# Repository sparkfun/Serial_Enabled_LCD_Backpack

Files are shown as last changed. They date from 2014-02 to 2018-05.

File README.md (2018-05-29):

Serial Enabled LCD Backpack
===========================

Serial Enabled LCD Backpack (https://cdn.sparkfun.com/assets/parts/2/0/0/00258-01a.jpg)

[*Serial Enabled LCD Backpack (LCD-00258)*](https://www.sparkfun.com/products/258)

This PIC-based serial enabled LCD backpack allows you to control a parallel based LCD over a single-wire serial interface. It is compatible with 16x2 LCDs and 20x4 LCDs.

Repository Contents
-------------------

* **/Firmware**
  * **/Arduino_Examples** - Arduino example code to control the PIC-based serial enabled LCD
  * **/Default_Firmware** - Any default firmware on the PIC that the part ships with for different size LCD screens
* **/Hardware** - All Eagle design files (.brd, .sch, .STL)

Documentation
--------------
* **[Hookup Guide](https://www.sparkfun.com/tutorials/246)** - Basic hookup guide for the PIC-based serial enabled LCD backpack.

Product Versions
----------------

* [LCD-00258](https://www.sparkfun.com/products/258) - SparkFun Serial Enabled LCD Backpack

* Built-In Serial Enabled LCD
  * [LCD-09067](https://www.sparkfun.com/products/9067) - Built-In SparkFun Serial Enabled 16x2 LCD - White on Black 3.3V
  * [LCD-09066](https://www.sparkfun.com/products/9066) - Built-In SparkFun Serial Enabled 16x2 LCD - Black on Green 3.3V
  * [LCD-09068](https://www.sparkfun.com/products/9068) - Built-In SparkFun Serial Enabled 16x2 LCD - Red on Black 3.3V
  * [LCD-09395](https://www.sparkfun.com/products/9395) - Built-In SparkFun Serial Enabled 16x2 LCD - Whote on Black 5V
  * [LCD-09568](https://www.sparkfun.com/products/9568) - Built-In SparkFun Serial Enabled 20x4 LCD - Black on Green 5V
  * [LCD-09394](https://www.sparkfun.com/products/9394) - Built-In SparkFun Serial Enabled 16x2 LCD - Red on Black 5V

License Information
-------------------
The hardware is released under [Creative Commons ShareAlike 4.0 International](https://creativecommons.org/licenses/by-sa/4.0/).
The code is beerware; if you see me (or any other SparkFun employee) at the local, and you've found our code helpful, please buy us a round!

Distributed as-is; no warranty is given.

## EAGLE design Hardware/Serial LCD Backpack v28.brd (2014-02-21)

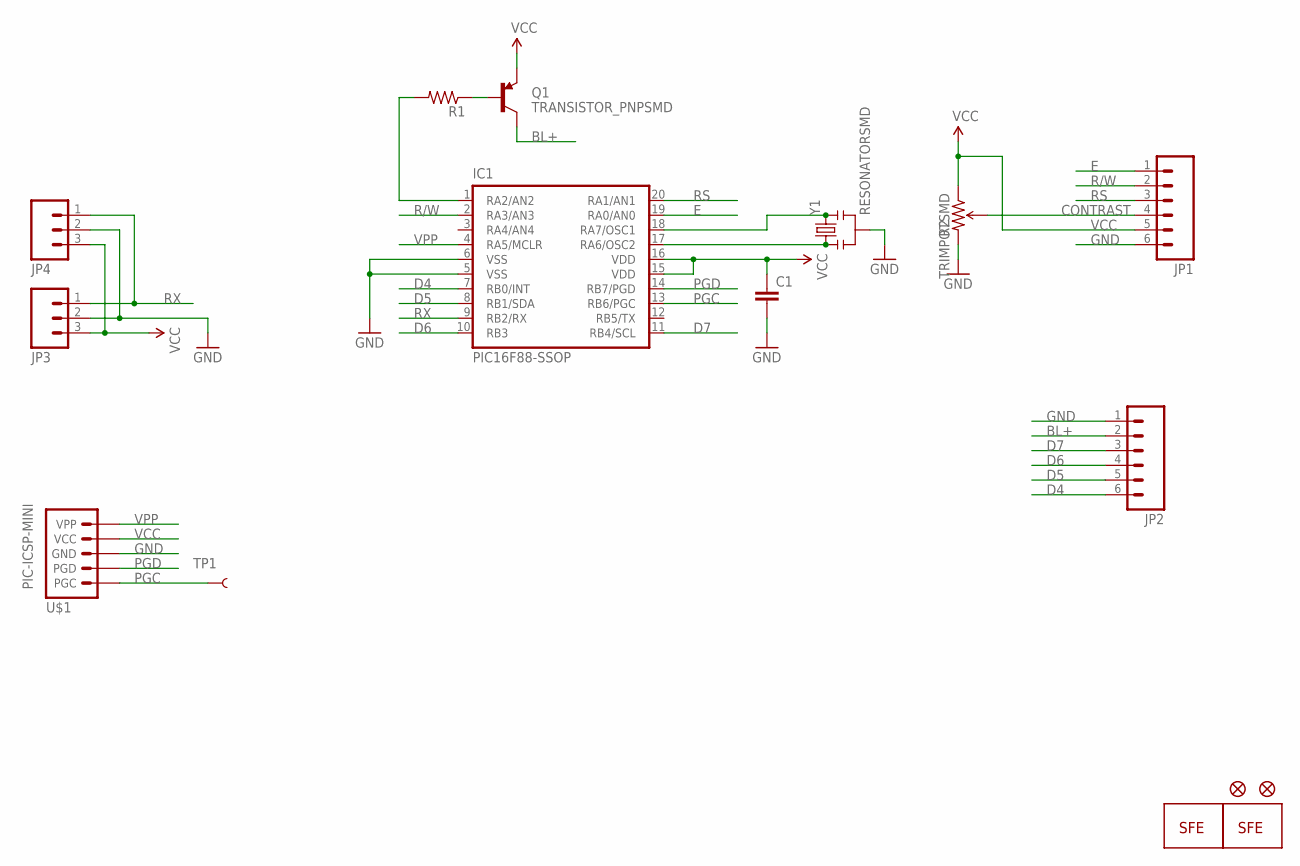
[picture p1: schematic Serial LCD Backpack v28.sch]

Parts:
C1: CAP0402-CAP; 0402-CAP
IC1: PIC16F88-SSOP; SSOP20
JP1, JP2: M06LOCK; 1X06_LOCK
JP3: M03PTH; 1X03
JP4: M03SCREW_LOCK; SCREWTERMINAL-3.5MM-3_LOCK.007S
Q1: TRANSISTOR_PNPSMD; SOT23-3
R1: RESISTOR0402-RES; 0402-RES
R2: TRIMPOTSMD; TRIMPOT-3MM
TP1: TEST-POINT3X5; PAD.03X.05
U$1: PIC-ICSP-MINI
U$2: LOGO-FLAME-LARGE
U$3, U$4: FIDUCIAL1X2; FIDUCIAL-1X2
U$5: LOGO-SFENEW; SFE-NEW-WEBLOGO
Y1: RESONATORSMD; RESONATOR-SMD

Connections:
BL+: JP2.2, Q1.3 (C)
CONTRAST: JP1.4, R2.2 (WIPER)
D4: IC1.7 (RB0/INT), JP2.6
D5: IC1.8 (RB1/SDA), JP2.5
D6: IC1.10 (RB3), JP2.4
D7: IC1.11 (RB4/SCL), JP2.3
E: IC1.19 (RA0/AN0), JP1.1
GND: C1.2, IC1.5 (VSS), IC1.6 (VSS), JP1.6, JP2.1, JP3.2, JP4.2, R2.3 (CW), U$1.3 (GND), Y1.2
unnamed: IC1.18 (RA7/OSC1), Y1.3
unnamed: IC1.17 (RA6/OSC2), Y1.1
unnamed: IC1.1 (RA2/AN2), R1.2
unnamed: Q1.1 (B), R1.1
PGC: IC1.13 (RB6/PGC), TP1.P$1, U$1.5 (PGC)
PGD: IC1.14 (RB7/PGD), U$1.4 (PGD)
R/W: IC1.2 (RA3/AN3), JP1.2
RS: IC1.20 (RA1/AN1), JP1.3
RX: IC1.9 (RB2/RX), JP3.1, JP4.1
VCC: C1.1, IC1.15 (VDD), IC1.16 (VDD), JP1.5, JP3.3, JP4.3, Q1.2 (E), R2.1 (CCW), U$1.2 (VCC)
VPP: IC1.4 (RA5/MCLR), U$1.1 (VPP)

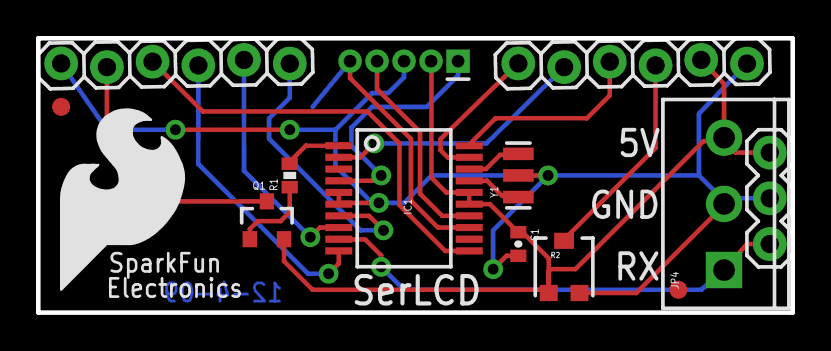
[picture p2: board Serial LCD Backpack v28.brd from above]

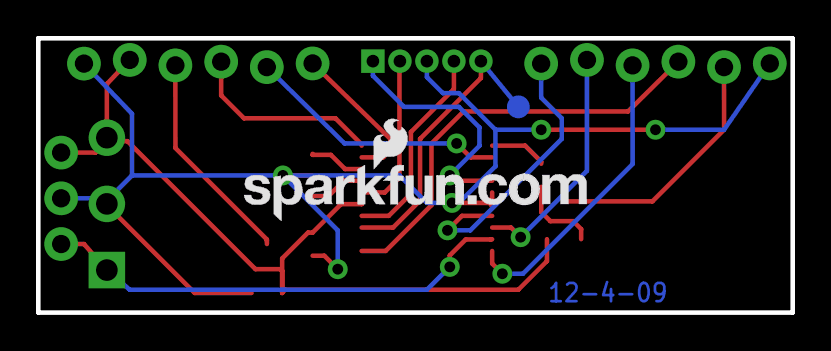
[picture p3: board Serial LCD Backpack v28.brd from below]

Board: 2 copper layers, 41.9 x 15.2 mm, 16 parts (2 on the bottom side), 19 nets.

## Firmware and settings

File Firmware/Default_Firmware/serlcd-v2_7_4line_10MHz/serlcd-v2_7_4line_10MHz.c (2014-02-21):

/*
    1-16-04
    Copyright Spark Fun Electronics© 2004
    
    Uses 16F688 to drive Parallel LCD with Serial Commands.
    
    For educational and hobbyist use only. NOT for commerical use.


    Thanks to Olimex for providing the original C test code for the PIC-MT-C w/ 16F873
    
    1-17-04 Started migrating 16F873A code to 16F630


    1-17-04pm Works well from user keyboard input. No busy flag checking yet.
              Ok, busy flag works.


    1-19-04 Got commands to pass through after decimal 254 is seen. The special 8-bit data
            mode command is also correctly ignored.
            
    1-30-04 v1.1 Added 16x4 line support
    
    2-10-04 v1.2 Added BL Control. Moved to direct RC0-RC3 = D4-D7 mapping. This significantly
            improved timing between characters.
    
    2-12-04 Added EEPROM recording of Backlight State. Also added Super Special
            Command input. Pass the '|' character to the LCD, then pass '1' to turn
            on/off backlight.
            
            Added universal support for any LCD upto 4 lines, 40 characters wide.
            
    2-16-04 New PCBs v1.1 - Replaced some if statements with EL1, EL2, etc, in the 4 line wrapping 
            routine to try to speed things up.
            
    2-17-04 v1.3 Timing has now been nearly reduced to within one stop bit. In the past, 
            wrapping characters were some times lost because of the time required to relocate 
            the cursor. Now almost all characters are seen, every time, every location. 
            There are stuff certain combinations that cause a character miss.
    
    3-3-04 New PCB - 1.1a. BL Control has been routed to PGC - bad idea. Causes problems with programming.
           Unit must be powered +5V while programming to get it to work. Will move this line on next revision.
           
    4-5-04 Customer reported problems with interface. Baud rate was too low. The test bed was running 
           at much too low of a speed. The test bed has been corrected, the code must now be tweaked.
           
    4-14-04 Added a special command 8 that will re-initialize the LCD. There are certain circumstances (low
            power) where the PIC will keep running, but the LCD will shut down. 


    6-1-04 Re-routed some pins for a smoother PCB layout. Firmware had to be updated.


    7-7-04 Added support for 40x2 displays
    
    12-15-04 New version - SerLCD v2 using 16F688
             Incoming characters buffered
             PWM of back light
             Turning off splash screen
             Higher data speeds
             
             We now use the 16F688 with onboard UART and internal 8MHz oscillator. The internal oscillator is much
             tighter tolerance and the UART interrupt is used. The incoming characters are automatically buffered,
             up to 80 characters can be stored at a time in case the LCD is busy doing other things.
             
             The backlight is now pulse width modulated. What this means is you can set how bright the backlight is
             from 0 (off) to 30 (completely on). This will greatly effect how much current the module uses while 
             retaining part of the ability to see in low light conditions. The backlight defaults to maximum 
             output (brightest) unless otherwise configured by the user. To control the backlight, send the 'special
             command' character (124) followed by 0b.100?.???? where ?? is the value from 0-30.
             
             You can now turn off the splash screen. Send the 'special command' character 124 followed by decimal 9.
             The splash screen option will toggle and will take effect the next time the LCD is initialized (power-up).
    
    3-30-05  Added busy checking before the LCD is init'd. SPBRG is set to 51 per datasheet for 16F688.
             Extended the delays a bit during LCD init to try to avoid hangups with 3% of units that report hanging.
    
    4/29/09  Changed code for integrated LCD with backpack, outsourced hardware. Control lines to LCD from PIC have changed.
    
*/


#define Clock_10MHz
#define Baud_9600
//#define DEBUG


#include "C:\Global\PIC\C\16F88.h"  // device dependent interrupt definitions
#include "C:\Global\PIC\C\int16CXX.H"



#pragma config|= 0x3F02
//#pragma config|= 0x2F8A   //10MHz xtal
//#pragma config|= 0x29D3     //int RC


//LCD Type
#define Display_16x2    0
#define Display_16x4    0


//Hardware port definitions
#define     RS              PORTB.4
#define     R_W             PORTB.1  
#define     BL_Control      PORTA.4
#define     E               PORTB.0

//#define     STAT            PORTA.4


#define     D4              PORTA.0
#define     D5              PORTA.1
#define     D6              PORTA.2
#define     D7              PORTA.3


//Constant definitions
#define     FALSE       0
#define     TRUE        1


#define     LCD_BACKLIGHT_SETTING   0
#define     LCD_WIDTH_SETTING       1
#define     LCD_LINE_SETTING        2
#define     LCD_BRIGHTNESS_SETTING  3
#define     LCD_SPLASH_ENABLE       4
#define     LINE1_START             5
#define     LINE2_START             25
#define     BAUD_RATE               45




#define     CLR_DISP        0b.0000.0001 //Clear display


#define     CUR_HOME        0b.0000.0010    //Move cursor home and clear screen memory
#define     CUR_RIGHT       0b.0001.0100    //Move cursor one to right
#define     CUR_LEFT        0b.0001.0000    //Move cursor one to left


#define     SCROLL_RIGHT    0b.0001.1100    //Scroll entire screen right one space
#define     SCROLL_LEFT     0b.0001.1000    //Scroll entire screen left one space


#define     DISP_ON         0b.0000.1100    //Turn visible LCD on
#define     DISP_OFF        0b.0000.1000    //Turn visible LCD off


#define     UNDERLINE_ON    0b.0000.1110    //Turn on underlined cursor
#define     UNDERLINE_OFF   0b.0000.1100    //Turn off underlined cursor


#define     BLINKCUR_ON     0b.0000.1101    //Turn on blinking box cursor
#define     BLINKCUR_OFF    0b.0000.1100    //Turn off blinking box cursor


#define     DUALCUR_ON      0b.0000.1111    //Turn on blinking box and underline cursor
#define     DUALCUR_OFF     0b.0000.1100    //Turn off blinking box and underine cursor


#define     SET_CURSOR      0b.1000.0000    //SET_CURSOR + X : Sets cursor position to X


#define     ENTRY_INC       0b.0000.0110 //
#define     DD_RAM_ADDR     0b.1000.0000 //
#define     DD_RAM_ADDR2    0b.1100.0000 //
#define     CG_RAM_ADDR     0b.0100.0000 //


//Global variable declarations
uns8 letter;
static uns8 cursor_position;
uns8 splash_enable;


uns8 backlight_counter;
uns8 brightness_setting;
uns8 Backlight_Setting;


uns8 LCD_Type;
uns8 LCD_Width;
uns8 LCD_Lines;
uns8 EL1, EL2, EL3, EL4;
uns8 CP1, CP2, CP3, CP4;
uns8 baud;


uns8 RX_In;
uns8 Displayed_Letters;


#pragma rambank 1
#define BUFFER_SIZE 80
uns8 RX_Array[BUFFER_SIZE];

#pragma rambank 0
uns8 line1[20];
uns8 line2[20];


//End Global variable declarations



//Interrupt Vectors
#pragma origin 4
interrupt serverX( void)
{
    int_save_registers
    char sv_FSR = FSR;  // save FSR if required


    if(RCIF) //If we have received something from the computer store it in the RX_Array array
    {
        
        RX_In++;
        if(RX_In == BUFFER_SIZE) RX_In = 0;
        
        RX_Array[RX_In] = RCREG;
    }


    if(T0IF) //TMR0 Overflow Interrupt - Occurs every 1024us ~1ms
    {
        backlight_counter++;


        if(backlight_counter == 30)
        {
            backlight_counter = 0; //30ms pulse width period
            
            if (brightness_setting > 0) BL_Control = 0; //Kick on the back light only if brightness setting is greater than 0
        }    


        //Turn off back light after its assigned duration
        if(backlight_counter == brightness_setting) BL_Control = 1; 
        
        T0IF = 0; //Clear Interrupt Flag
    }
    
    FSR = sv_FSR;               // restore FSR if saved
    int_restore_registers 
}


//Function declarations
void boot_up(void);
void special_commands(void);
void delay_ms(uns16);
void delay_ms(uns16);
uns8 onboard_eeread(uns8 e_address);
void onboard_eewrite(uns8 e_data, uns8 e_address);
void set_baud_rate(void);


void send_char(uns8);
void send_cmd(uns8);
void send_string(const char* incoming_string);
void LCD_wait(void);
void init_lcd(void);


//#include "C:\Global\PIC\C\stdio.c"

//End Function declarations


void main(void)
{
    //Initialize LCD and PIC
    boot_up();
    
    while(1)
    {
        //sleep(); //Wait for incoming command to wake us up...
        //nop(); //Executes after wake-up and before INTF runs
        
        if(RX_In != Displayed_Letters)
        {
            Displayed_Letters++;
            if(Displayed_Letters == BUFFER_SIZE) Displayed_Letters = 0;


            letter = RX_Array[Displayed_Letters];



            //Check for special LCD command
            //===============================================================
            if (letter == 254)
            {
                //Wait for the next letter
                while(RX_In == Displayed_Letters);
                
                //Look at the next letter
                Displayed_Letters++;
                if(Displayed_Letters == BUFFER_SIZE) Displayed_Letters = 0;


                letter = RX_Array[Displayed_Letters];
                
                //Ignore the one command that will send the LCD into 8-bit mode
                if ( (letter >> 4) != 3 ) //If not 0b.0000.0011, then send it to LCD
                    send_cmd(letter);
                    
                //Correct cursor position variable if certain commands are received
                if (letter == CLR_DISP)
                    cursor_position = 0;
                else if (letter.7 == 1) //Move cursor command
                    cursor_position = letter & 0b.0111.1111; //Ignore first bit - obtain address
            }    
            //===============================================================


            //Super Special LCD Commands
            //===============================================================
            else if (letter == 124) //This is the '|' character above '\'
            {
                //Wait for the next letter
                while(RX_In == Displayed_Letters);


                //Look at the next letter
                Displayed_Letters++;
                if(Displayed_Letters == BUFFER_SIZE) Displayed_Letters = 0;


                letter = RX_Array[Displayed_Letters];


                special_commands();
            }
            //===============================================================
            
            
            
            //All else, just print it to the LCD and adjust the cursor position
            //===============================================================
            else
            {   
                #ifdef DEBUG  
                    if (letter == '+') brightness_setting++;
                    if (brightness_setting > 30) brightness_setting = 0;
                    
                    if( letter == 'A')
                    {
                        letter = 0b.1000.0000 | 15;
                        special_commands();
                    }
                #endif
                
                
                
                
//Backspace============================================================================                
                if (letter == 8)
                {
                    
                    if(cursor_position == (LCD_Width + 64))        //from beginning of line 4
                    {
                        //send_cmd(CP3);
                        send_cmd(CP3 + LCD_Width - 1);
                        send_char(32);
                        send_cmd(CP3 + LCD_Width - 1);
                        cursor_position = EL3 - 1;
                        
                        //printf("%d\r\n",cursor_position);
                    }
                    
                    else if(cursor_position == LCD_Width)   //from beginning of line 3
                    {
                        //send_cmd(CP2);
                        send_cmd(CP2 + LCD_Width - 1);
                        send_char(32);
                        send_cmd(CP2 + LCD_Width - 1);
                        cursor_position = EL2 - 1;
                        
                        line2[cursor_position - 64] = 32;
                        
                        //printf("%d\r\n",cursor_position);
                    }
                    
                    
                    else if(cursor_position == 64)      //from beginning of line 2
                    {
                        
                        //send_cmd(CP1);
                        send_cmd(CP1 + LCD_Width - 1);
                        send_char(32);
                        send_cmd(CP1 + LCD_Width - 1);
                        cursor_position = EL1 - 1;
                        
                        line1[cursor_position] = 32;
                        
                        //printf("%d\r\n",cursor_position);
                    
                    }
                        
                    else if (cursor_position == 0)      //from beginning of line 1
                    {
                        if(LCD_Lines == 1)
                        {
                            send_cmd(CP1 + LCD_Width - 1);
                            send_char(32);
                            send_cmd(CP1 + LCD_Width - 1);
                            cursor_position = EL1 - 1;
                            
                            //printf("%d\r\n",cursor_position);
                        }
                        
                        else if (LCD_Lines == 2)                      
                        {
                            //send_cmd(CP2);
                            send_cmd(CP2 + LCD_Width - 1);
                            send_char(32);
                            send_cmd(CP2 + LCD_Width - 1);
                            cursor_position = EL2 - 1;
                            
                            //printf("%d\r\n",cursor_position);
                        }
                        
                        else    //4 line display
                        {
                            //send_cmd(CP4);
                            send_cmd(CP4 + LCD_Width - 1);
                            send_char(32);
                            send_cmd(CP4 + LCD_Width - 1);
                            cursor_position = EL4 - 1;
                            
                            //printf("%d\r\n",cursor_position);
                        }
                    }
                    
                    else
                    {
                        send_cmd(CUR_LEFT);
                        send_char(32);
                        send_cmd(CUR_LEFT);
                        cursor_position--;
                        
                        //make sure that the line arrays are correct
                        if (cursor_position < 16) line1[cursor_position] = 32;
                        if ((cursor_position > 63) && (cursor_position < 80)) line2[cursor_position - 64] = 32;
                        
                        //printf("%d\r\n",cursor_position);
                    }
                }
                
                
//Regular character send==========================================================================
                else
                {
                    send_char(letter);
                    
                    //keep the first 2 lines logged for splash screen changes
                    if (cursor_position < 20) line1[cursor_position] = letter;
                    if ((cursor_position > 63) && (cursor_position < 84)) line2[cursor_position - 64] = letter;
    
                    cursor_position++;
                    
                    
                    //When the cursor gets to the end of one line, it must
                    //advance to the next visual line
                    //===============================================================
                    if (cursor_position == EL1) //End of line one
                    {
                        if(LCD_Lines == 1)
                        {
                            cursor_position = 0; //Return to beginning of line 1
                            send_cmd(CP1);
                        }
                        else
                        {
                            cursor_position = 64; //Beginning of line 2
                            send_cmd(CP2);
                        }
                    }
                    
                    else if (cursor_position == EL2) //End of line 2
                    {
                        if(LCD_Lines == 2)
                        {
                            cursor_position = 0; //Return to line 1
                            send_cmd(CP1);
                        }
                        else
                        {
                            cursor_position = LCD_Width; //Beginning of line 3
                            send_cmd(CP3);
                        }
                    }
                    
                    else if (cursor_position == EL3) //End of line 3
                    {
                        cursor_position = EL2; //Beginning of line 4 is the end of line 2
                        send_cmd(CP4);
                    }
                    
                    else if (cursor_position == EL4) //End of line 4
                    {
                        cursor_position = 0; //Beginning of line 1
                        send_cmd(CP1);
                    }
                    
                    
                
                }
                //===============================================================
            }
            //===============================================================
                


        }//End regular character printing
            
   }//End infinite loop


}//End Main
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

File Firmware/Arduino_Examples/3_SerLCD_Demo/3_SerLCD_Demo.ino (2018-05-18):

/***********************************************************************
  SerLCD Demo Example 3
  Written by: Joel Bartlett @ SparkFun Electronics
  Date: December 20, 2012
  Modified by: Ho Yun "Bobby" Chan @ SparkFun Electronics
  Date: May 3, 2018

  This code uses the information presented in the SerLCD Datasheet
  to create an Arduino example using the SerLCD from SparkFun Electonics.
  Each of the SerLCD's capabilities is broken up into seperate functions
  within the sketch. Simply call each function with the correct parameters
  to get the desired result form the LCD screen.

  This code was developed for the Arduino IDE v102

  To use, connect the following pins
    VDD -> 5V
    GND -> GND
    LCD RX -> Arduino TX (pin 11)

    ***Don't forget to disconnect the LCD's RX pin from the TX pin of
  the Arduino's UART line while programming!***

  You can also check out the SerLCD library from Arduino
  http://playground.arduino.cc/Code/SerLCD

  If you need to reprogram often, or need the UART for another device,
  you can use the Software Serial libary to create a
  seperate UART for the LCD.
  Arduino IDE -> Skecth -> Import Library ->Software Serial

  To declare a new UART using SoftwareSerial, insert this line:
  SoftwareSerial NAME(x,y); // RX, TX
  where Name is the name of the new UART, x is the RX pin, and y is the TX     pin.

  "THE BEER-WARE LICENSE"
  As long as you retain this notice you can do whatever you want with this     stuff.
  If we meet some day, and you think this stuff is worth it, you can buy me     a beer.
************************************************************************/
#include <SoftwareSerial.h>

SoftwareSerial LCD(10, 11); // Arduino SS_RX = pin 10 (unused), Arduino SS_TX = pin 11

//-------------------------------------------------------------------------------------------
void setup()
{
  LCD.begin(9600);// all SerLCDs come at 9600 Baud by default
}
//-------------------------------------------------------------------------------------------
void loop()
{
  scrollingMarquee();
  tempAndHumidity();
  counter();
  backlight();
  cursors();
}
//-------------------------------------------------------------------------------------------
void clearScreen()
{
  //clears the screen, you will use this a lot!
  LCD.write(0xFE);
  LCD.write(0x01);
}
//-------------------------------------------------------------------------------------------
void selectLineOne()
{
  //puts the cursor at line 0 char 0.
  LCD.write(0xFE); //command flag
  LCD.write(128); //position
}
//-------------------------------------------------------------------------------------------
void selectLineTwo()
{
  //puts the cursor at line 0 char 0.
  LCD.write(0xFE); //command flag
  LCD.write(192); //position
}
//-------------------------------------------------------------------------------------------
void moveCursorRightOne()
{
  //moves the cursor right one space
  LCD.write(0xFE); //command flag
  LCD.write(20); // 0x14
}
//-------------------------------------------------------------------------------------------
void moveCursorLeftOne()
{
  //moves the cursor left one space
  LCD.write(0xFE); //command flag
  LCD.write(16); // 0x10
}
//-------------------------------------------------------------------------------------------
void scrollRight()
{
  //same as moveCursorRightOne
  LCD.write(0xFE); //command flag
  LCD.write(20); // 0x14
}
//-------------------------------------------------------------------------------------------
void scrollLeft()
{
  //same as moveCursorLeftOne
  LCD.write(0xFE); //command flag
  LCD.write(24); // 0x18
}
//-------------------------------------------------------------------------------------------
void turnDisplayOff()
{
  //this tunrs the display off, but leaves the backlight on.
  LCD.write(0xFE); //command flag
  LCD.write(8); // 0x08
}
//-------------------------------------------------------------------------------------------
void turnDisplayOn()
{
  //this turns the dispaly back ON
  LCD.write(0xFE); //command flag
  LCD.write(12); // 0x0C
}
//-------------------------------------------------------------------------------------------
void underlineCursorOn()
{
  //turns the underline cursor on
  LCD.write(0xFE); //command flag
  LCD.write(14); // 0x0E
}
//-------------------------------------------------------------------------------------------
void underlineCursorOff()
{
  //turns the underline cursor off
  LCD.write(0xFE); //command flag
  LCD.write(12); // 0x0C
}
//-------------------------------------------------------------------------------------------
void boxCursorOn()
{
  //this turns the box cursor on
  LCD.write(0xFE); //command flag
  LCD.write(13); // 0x0D
}
//-------------------------------------------------------------------------------------------
void boxCursorOff()
{
  //this turns the box cursor off
  LCD.write(0xFE); //command flag
  LCD.write(12); // 0x0C
}
//-------------------------------------------------------------------------------------------
void toggleSplash()
{
  //this toggles the splash screen
  //if off send this to turn on
  //if on send this to turn off
  LCD.write(0x7C); //command flag = 124 dec
  LCD.write(9); // 0x09
}
//-------------------------------------------------------------------------------------------
int backlight(int brightness)// 128 = OFF, 157 = Fully ON, everything in between = varied brightness
{
  //this function takes an int between 128-157 and turns the backlight on accordingly
  LCD.write(0x7C); //NOTE THE DIFFERENT COMMAND FLAG = 124 dec
  LCD.write(brightness); // any value between 128 and 157 or 0x80 and 0x9D
}
//-------------------------------------------------------------------------------------------
void scrollingMarquee()
{
  //This function scroll text across the screen on both lines
  clearScreen(); // it's always good to clear the screen before moving onto a new print
  for (int j = 0; j < 17; j++)
  {
    selectLineOne();
    for (int i = 0; i < j; i++)
      moveCursorRightOne();
    LCD.print("SPARK");
    selectLineTwo();
    for (int i = 0; i < j; i++)
      moveCursorRightOne();
    LCD.print(" FUN");
    delay(500); // you must have a delay, otherwise the screen will print and clear before you can see the text
    clearScreen();
  }
}
//-------------------------------------------------------------------------------------------
void counter()
{
  //this function prints a simple counter that counts to 10
  clearScreen();
  for (int i = 0; i <= 10; i++)
  {
    LCD.print("Counter = ");
    LCD.print(i, DEC);
    delay(500);
    clearScreen();
  }
}
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

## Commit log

2014-02-21 Initial hardware and firmware files commited
    [Serial LCD Backpack v28.brd, Serial LCD Backpack v28.sch]
2018-05-18 Update Example 2
    Update example 2 file name. It was not opening correctly with the Arduino IDE.
    [2_MoveTheCursor.ino]
2018-05-18 Update Example 3 Comments
    * Correct spelling and grammar.
    * Auto indent code
    [3_SerLCD_Demo.ino]
2018-05-18 Update Arduino Paths to Same Folder
